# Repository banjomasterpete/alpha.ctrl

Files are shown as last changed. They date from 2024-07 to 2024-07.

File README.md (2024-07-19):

# alpha.ctrl
An open source Sysex controller for the Roland Alpha Juno

The Alpha Juno is a classic synthesizer with patches ranging from lush pads to the ‘Hoover’, but it’s also annoying to program. All parameter changes are done using 2 membrane keys and the alpha dial, this is adequate for making small changes but building patches from scratch can turn to agony. If it was the 80’s, the Alpha Juno could have been purchased with the optional programmer, the PG-300. This controller was specifically built for the Alpha 1 and 2 and restored the individual parameter change functions of previous Junos. In the 2020’s however, the PG-300s are often going for twice the price of the Juno, if you can even find one! There are other options available in software applications, custom MIDI controller layouts, and a few third party controllers. I’ve found the third party controllers to be unavailable or nearly as expensive as the originals, so this led me to design my own instead.

The alpha.ctrl can be built inexpensively, and its open source design makes it further modifiable by each user. I really encourage anyone to make modifications to it, I’m sure there are further optimizations to make than I could find.

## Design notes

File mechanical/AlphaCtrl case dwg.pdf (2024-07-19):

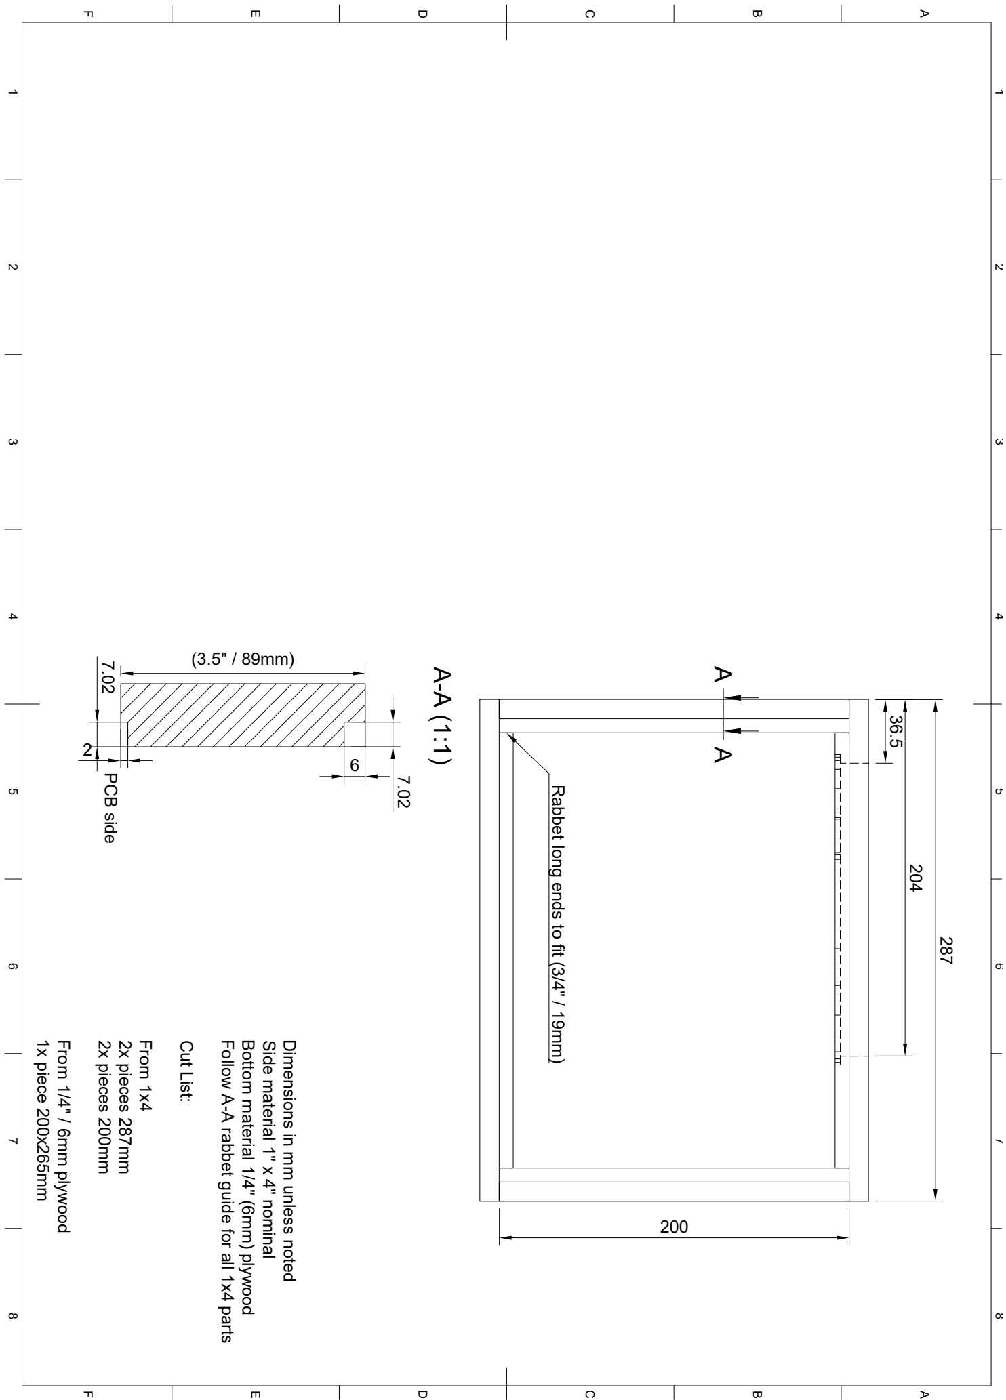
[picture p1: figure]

### 1 A 2 3 4 5 6 7 8 1 2 3 4 5 6 7 8 FEDCB FEDCBA 287

200 A-A (1:1) | A A2 PCB side | 6 | 7.02 7.02 1x piece 200x265mm From 1/4" / 6mm plywood | 2x pieces 200mm ²x pieces 287mm From 1x4 | Cut List: | Follow A-A rabbet guide for all 1x4 parts Bottom material 1/4" (6mm) plywood Side material 1" x 4" nominal Dimensions in mm unless noted
(3.5" / 89mm) | Rabbet long ends to fit (3/4" / 19mm) | 36.5 204

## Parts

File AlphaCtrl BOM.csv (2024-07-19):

Item | Qty | Reference(s) | Value | LibPart | Footprint | Tayda Part Number
1 | 1 | A1 | Arduino_Nano_Socket | arduino-library:Arduino_Nano_Socket | arduino-library:Arduino_Nano_Socket
2 | 2 | C1, C2 | 10u | Device:C_Polarized | Capacitor_THT:CP_Radial_D6.3mm_P2.50mm | ~
3 | 17 | C3, C4, C5, C6, C7, C8, C9, C10, C11, C12, C13, C14, C15, C16, C17, C18, C19 | 100n | Device:C | Capacitor_THT:C_Disc_D5.0mm_W2.5mm_P5.00mm | ~
4 | 1 | D1 | 1N914 | Diode:1N914 | Diode_THT:D_DO-35_SOD27_P7.62mm_Horizontal
5 | 1 | D2 | 1N4001 | Diode:1N4001 | Diode_THT:D_DO-41_SOD81_P10.16mm_Horizontal
6 | 1 | J1 | PWR | Connector_Generic:Conn_01x03 | Connector_BarrelJack:BarrelJack_Horizontal | A-3974
7 | 2 | MIDI_IN1, MIDI_OUT1 | ~ | Connector_Generic:Conn_01x07 | SynthParts:MIDI | A-1010
8 | 2 | PROG1, PWRSW1 | ~ | Connector_Generic:Conn_01x02 | Connector_PinHeader_2.54mm:PinHeader_1x02_P2.54mm_Vertical | ~
9 | 2 | R1, R2 | 10k | Device:R | Resistor_THT:R_Axial_DIN0207_L6.3mm_D2.5mm_P10.16mm_Horizontal | ~
10 | 24 | R3, R4, R5, R6, R7, R8, R9, R10, R11, R12, R13, R14, R15, R16, R17, R18, R19, R20, R21, R22, R23, R24, R25, R26 | 33k | Device:R | Resistor_THT:R_Axial_DIN0207_L6.3mm_D2.5mm_P10.16mm_Horizontal | ~
11 | 10 | R27, R28, R29, R30, R31, R32, R33, R34, R35, R36 | 20k | Device:R | Resistor_THT:R_Axial_DIN0207_L6.3mm_D2.5mm_P10.16mm_Horizontal | ~
12 | 4 | R37, R38, R39, R40 | 220R | Device:R | Resistor_THT:R_Axial_DIN0207_L6.3mm_D2.5mm_P10.16mm_Horizontal | ~
13 | 2 | R41, R42 | 1k | Device:R | Resistor_THT:R_Axial_DIN0207_L6.3mm_D2.5mm_P10.16mm_Horizontal | ~
14 | 25 | RV1, RV2, RV3, RV4, RV5, RV6, RV7, RV8, RV9, RV10, RV11, RV12, RV13, RV14, RV15, RV16, RV17, RV18, RV19, RV20, RV21, RV22, RV23, RV24, RV25 | 100k | Device:R_Potentiometer | Potentiometer_THT:Potentiometer_Bourns_PTV09A-1_Single_Vertical | X-3547
15 | 2 | SW1, SW2 | ~ | :JunoBtn_1 | SynthParts:JunoButtons | X-4850
16 | 10 | T1 - T10 | ~ | :SP8T_1 | RotarySwitch:Switch_Rotary 8POS | A-5950
17 | 5 | U1, U2, U3, U4, U5 | 4051 | 4xxx:4051 | Package_DIP:DIP-16_W10.16mm_LongPads
18 | 1 | U6 | 6N138 | Isolator:6N138 | Package_DIP:DIP-8_W7.62mm_LongPads
19 | 1 | U7 | L7805 | Regulator_Linear:L7805 | Package_TO_SOT_THT:TO-220-3_Vertical
20 | 2 | Jumpers |  | 2x1 0.1 inch header jumpers |  | A-1324
21 | 1 | 8 pin DIP socket
22 | 5 | 16 pin DIP socket
23 | 1 | female pinheaders (or arduino socket) |  | 0.1 inch female pinheaders
24 | 1 | Power rocker switch |  |  |  | A-6103
25 | 1 | DC Wall wart, 9V DC 1A center positive 5x2.5
26 | 35 | knobs |  | whatever kind you want!
27 | 6 | M3 wood screw |  | M3 x 10 | To mount the panel to the case
28 | 2 | M3 machine screw & nut |  | M3 x 10 | To mount the power switch to the case

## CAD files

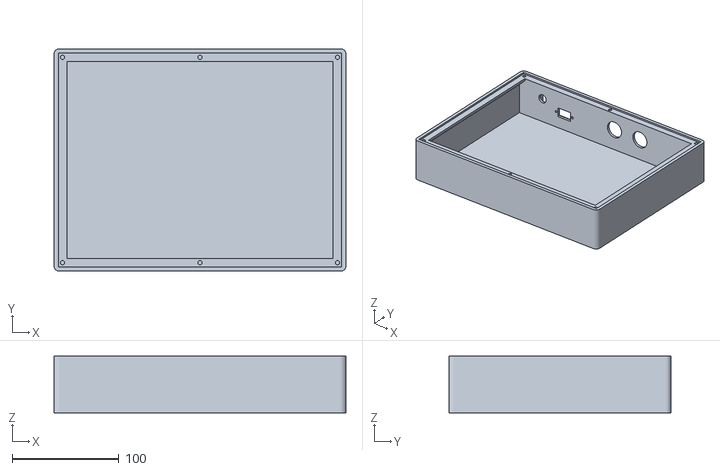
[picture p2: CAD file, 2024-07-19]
mechanical/AlphaCasePrint.stl
273.0 x 208.0 x 53.0

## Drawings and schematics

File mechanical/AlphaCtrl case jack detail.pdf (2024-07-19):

18

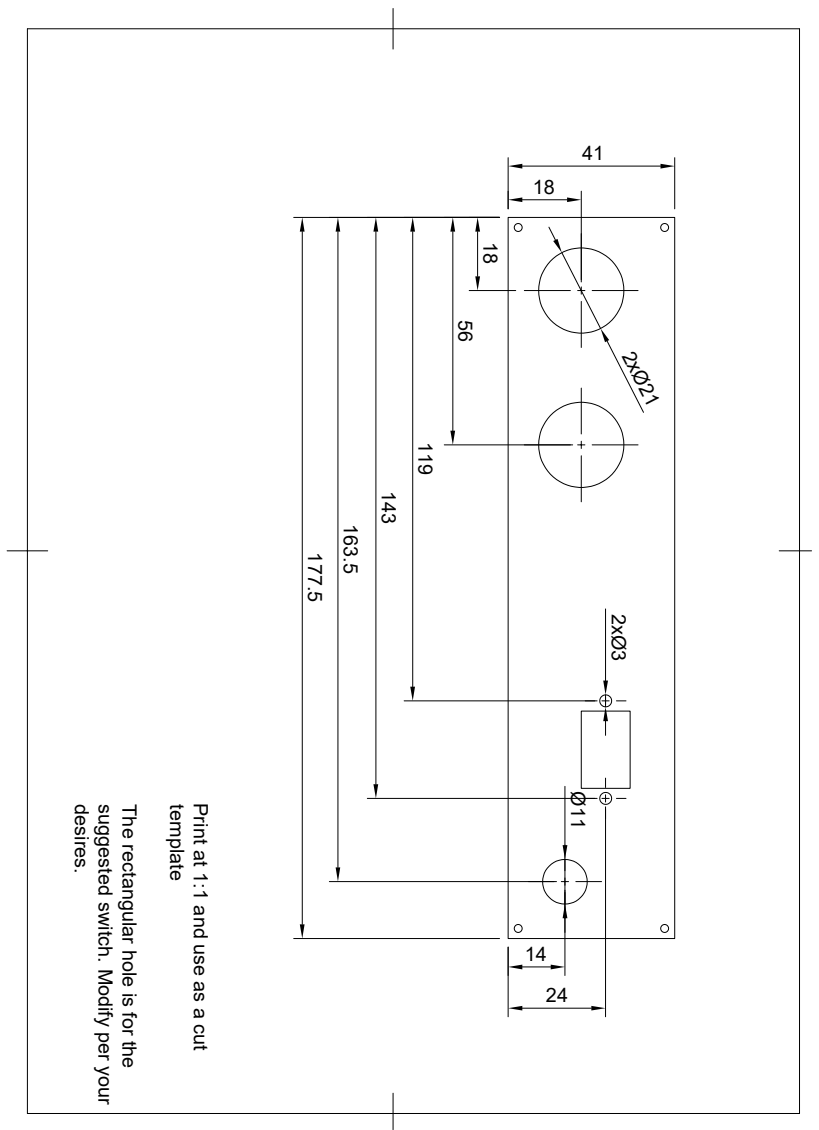
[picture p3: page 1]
2xØ21 2xØ3 Ø11 desires. suggested switch. Modify per your The rectangular hole is for the; template Print at 1:1 and use as a cut

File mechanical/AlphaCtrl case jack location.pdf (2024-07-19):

# 45 31.5 Sits against panel 6 9

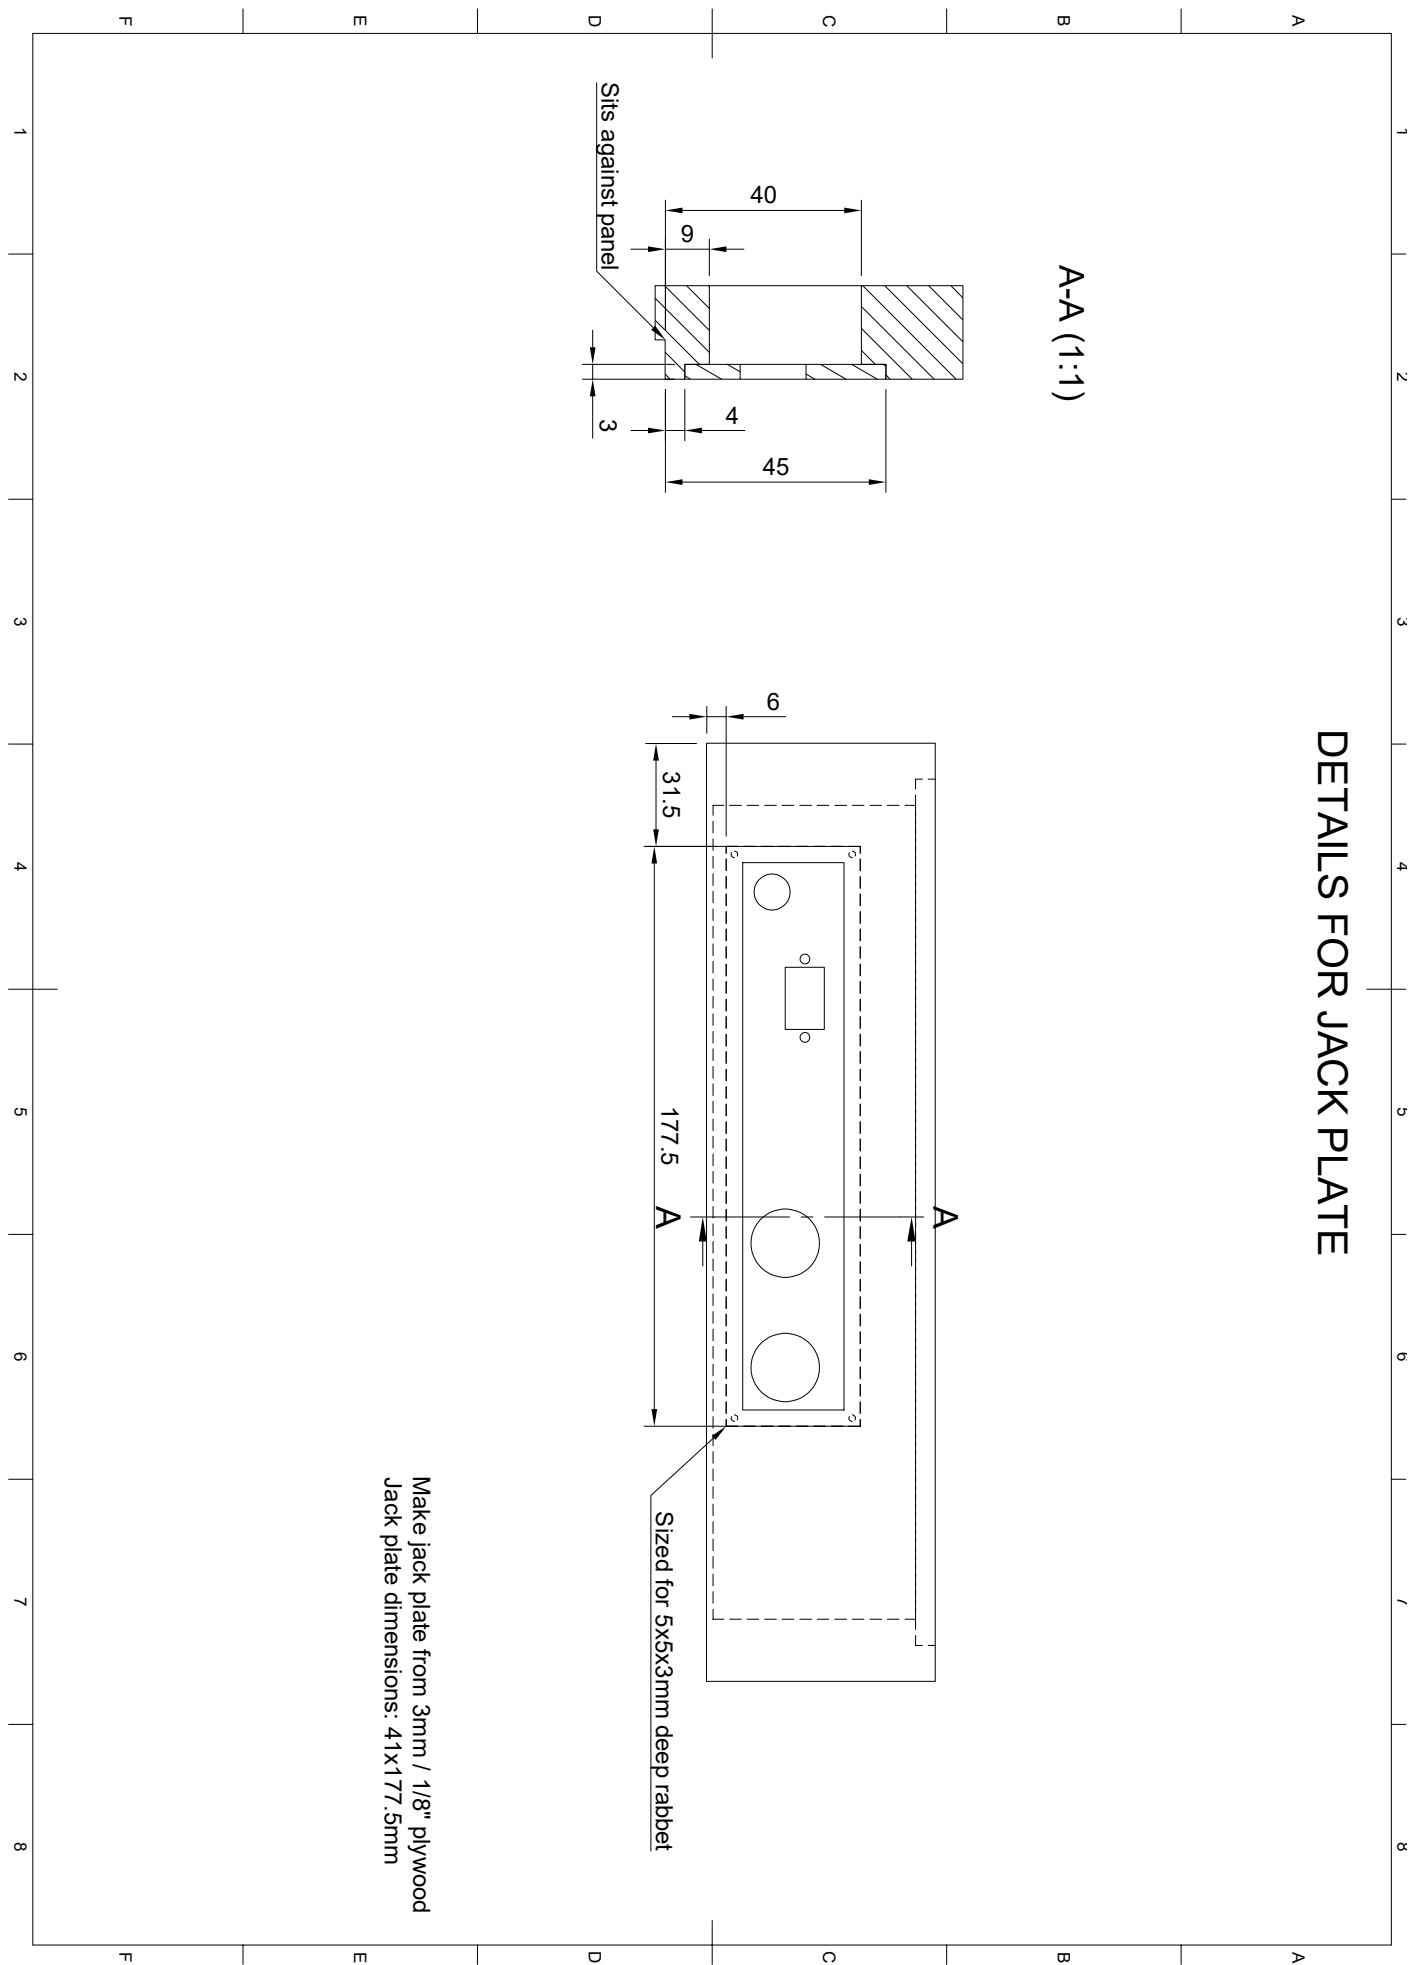
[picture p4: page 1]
DETAILS FOR JACK PLATE ³; 177.5 Jack plate dimensions: 41x177.5mm Make jack plate from 3mm / 1/8" plywood

1 A 2 3 4 5 6 7 8 1 2 3 4 5 6 7 8 FEDCB FEDCBA AA A-A (1:1) Sized for 5x5x3mm deep rabbet 4

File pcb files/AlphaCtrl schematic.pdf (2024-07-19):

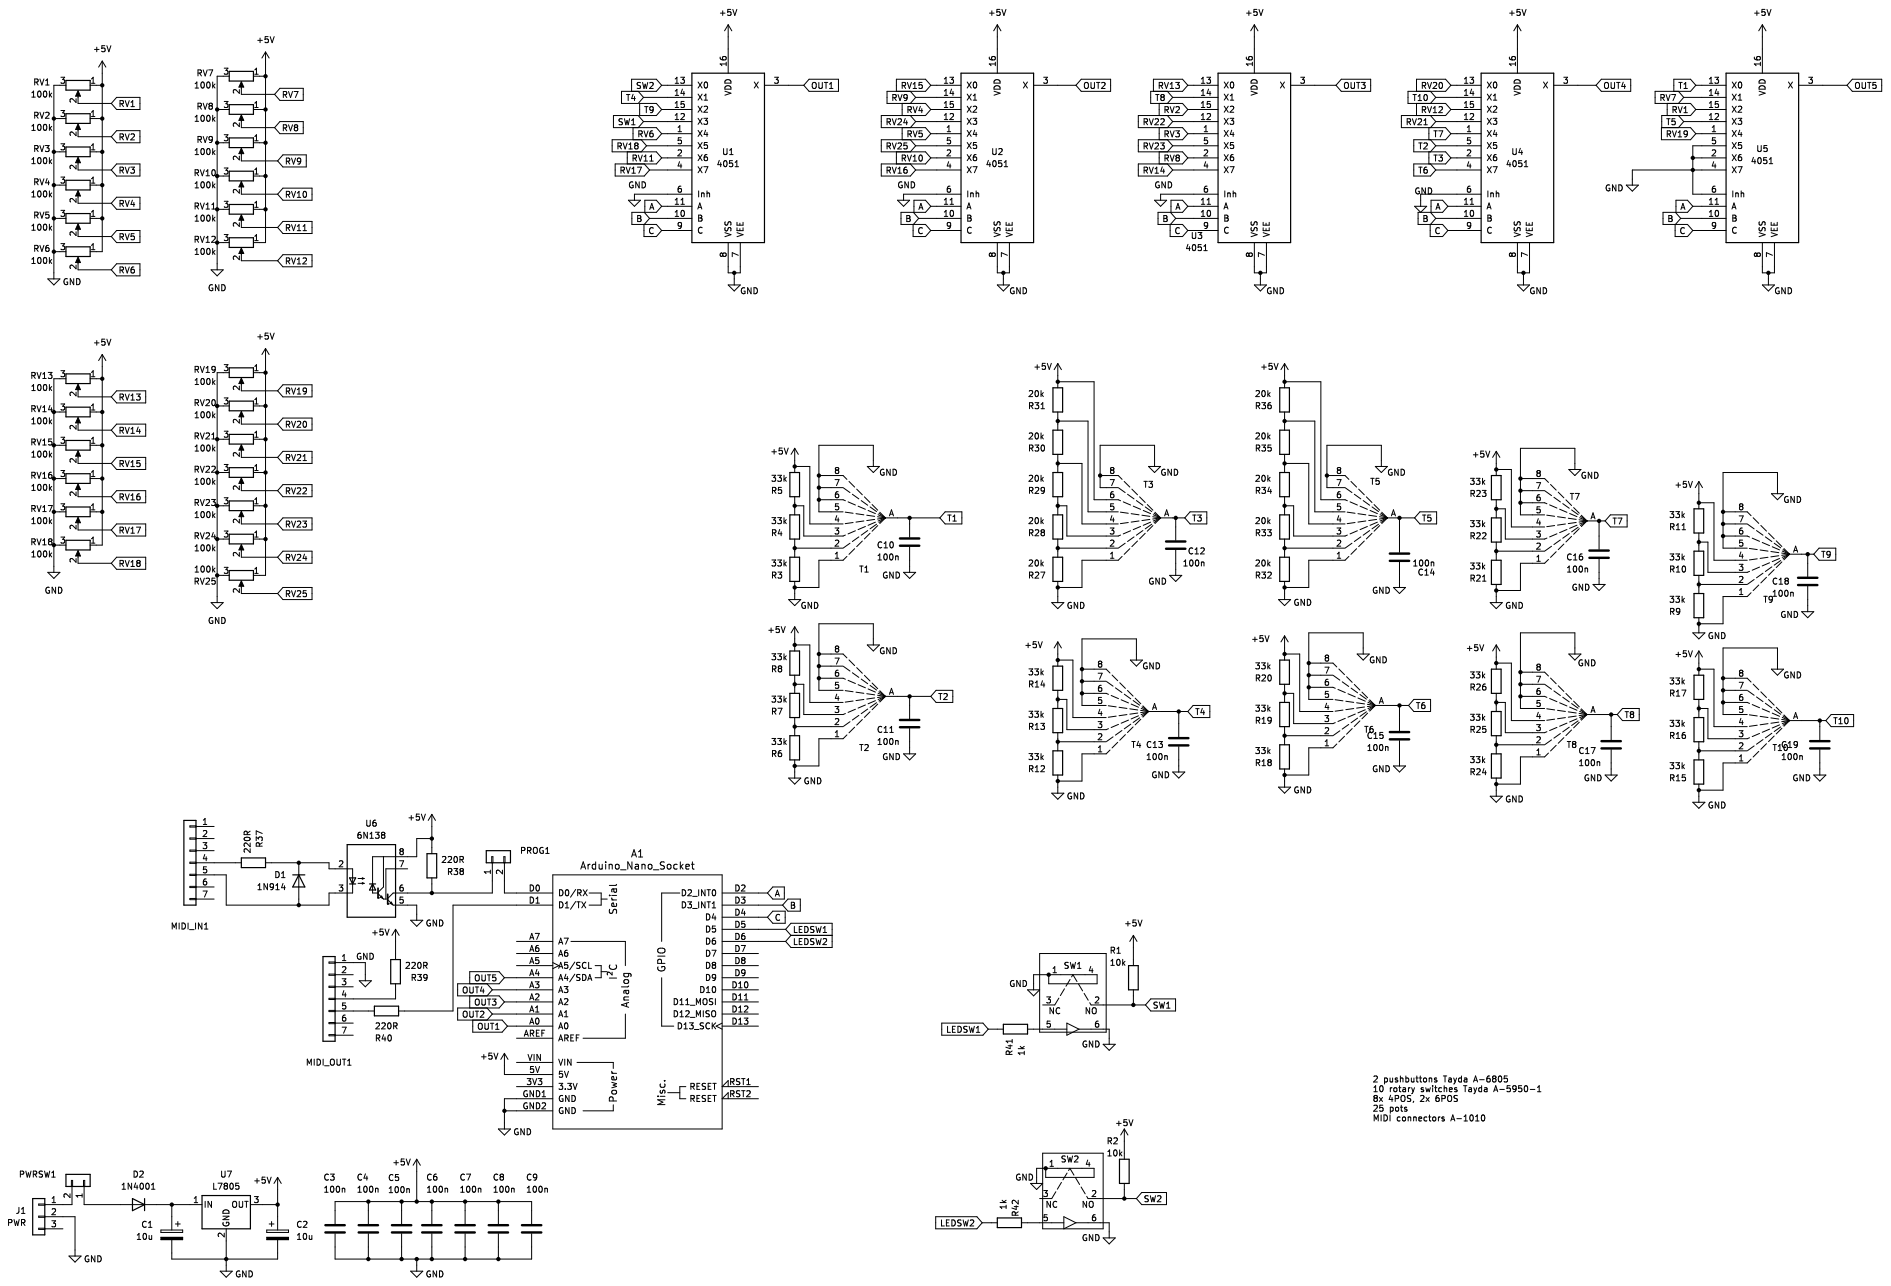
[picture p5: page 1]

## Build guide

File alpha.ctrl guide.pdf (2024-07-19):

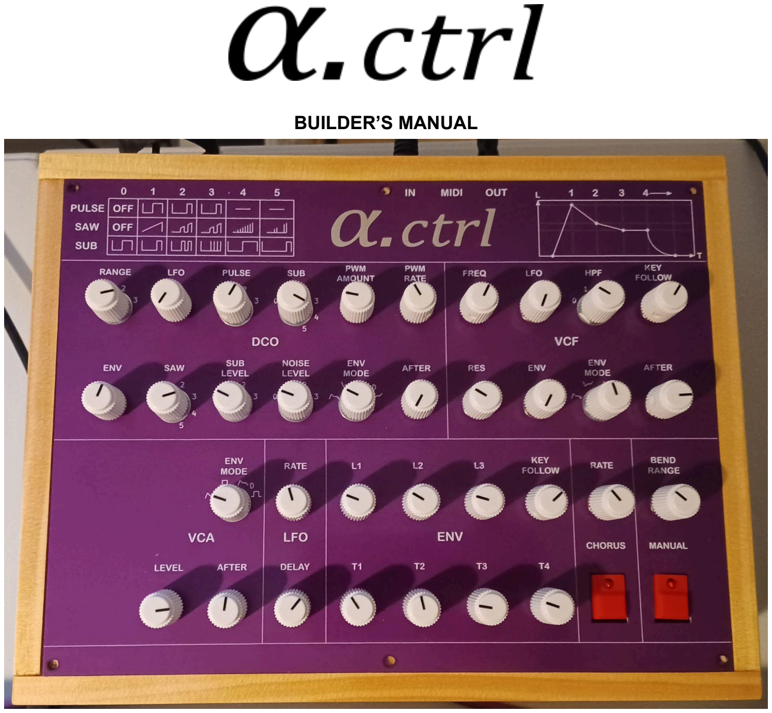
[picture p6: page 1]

BUILDER’S MANUAL

Build Guide
Order parts per the Bill of Materials, I was able to find all the parts on Tayda. Soldering the board components first (resistors, capacitors, chip sockets, etc.) before the panel components will leave you more room to work. The Bill of Materials contains the information needed to match each resistor number to its value. All of the ceramic capacitors are the same value throughout the board. Sockets are suggested for the multiplexers, optocoupler, and the Arduino. The jacks (power barrel jack, MIDI jacks) and the Arduino are soldered to the back side of the circuit board (the side the resistors go on). Pay attention to the silkscreen and you’ll be okay.

An Assembled Unit

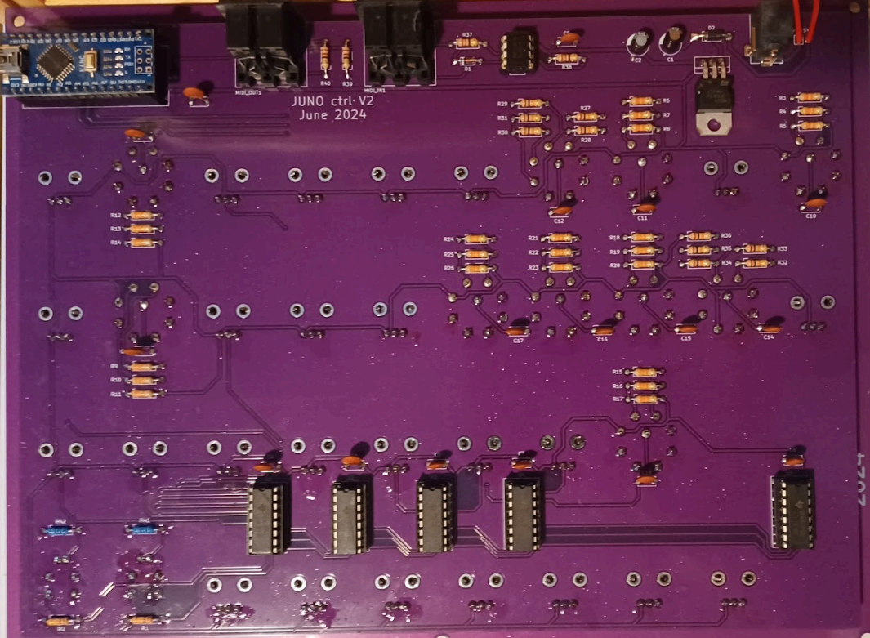
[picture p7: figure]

Before soldering panel components, attach the panel with the nuts from the pots & switches. This will ensure that all of the panel parts are aligned. The buttons can be finicky, solder 1 leg and maneuver it as needed with your off hand to get it aligned perfectly.

There are 2 sets of 2 pin jumpers: PWR and PROG. PWR is intended to be shorted with a rocker switch, any sort will do. PROG is necessary to disconnect the serial port from the MIDI circuit when the Arduino is being programmed. If the Arduino refuses to be programmed, make sure the PROG jumper is not connected!

PROG

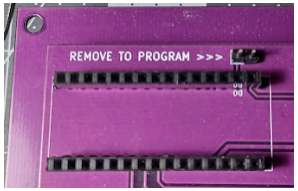
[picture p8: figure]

PWR

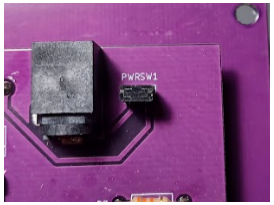
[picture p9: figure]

Speaking of power, the alpha.ctrl is powered by a 9V DC center positive wall wart. You probably have one of those laying around, right?

Enclosure
I opted to make a case out of some wood, mostly because my 3D printer is too small to make an enclosure this large. If you have a printer large enough, go for it! Mechanical drawings and an stl file are included in the repository.

Modifications
The jumpers can be removed if necessary. PWR can be replaced with a jumper wire, this will mean that the unit is always ON while the barrel jack is inserted. PROG can be replaced with a wire jumper, this means that the Arduino will need to be removed in order to program.

It may be desirable to mount the power and MIDI jacks directly to a separate panel instead of soldering to the circuit board. This could be helpful if you plan to use an alternative style of enclosure. Follow the schematic to determine where the pins should go.

Instead of running the MIDI channel change routine, I considered locating a DIP switch on the back side that would set the MIDI channel. This would, of course, require changes to the code.

Operations

The alpha.ctrl has 3 primary functions: individual parameter change, all parameter change, and MIDI channel change.These functions are the same as in the PG-300 owner’s manual.

NOTE: if no parameter changes are detected during operation, confirm that the MIDI EXCLUSIVE setting in the MIDI menu of the Juno is set to ON. The Juno will not accept parameter change messages if this setting is OFF.

Individual Parameter Change
Just move a control! The alpha.ctrl sends a Sysex message for each control change on the panel. These controls are the same as the parameter menu on the Juno, except now they’re easier to get to. All parameters work the same way they do per the Juno manual.

All Parameter Change
Pressing the Manual button will send the value of every control in its current location. You can think of this as a ‘hardware preset’ stored outside of the Juno’s memory. This control is necessary because the alpha.ctrl only sends a command when a parameter change is detected. If the Manual button is pressed accidentally, this change can be undone by reloading the preset.

MIDI Channel Change
The default MIDI channel of the alpha.ctrl is channel 1. In order to change this, power OFF the alpha.ctrl, set Noise Level and Sub Level as shown per the below table, then power ON the alpha.ctrl while holding the Manual button. The MIDI channel change is confirmed by 2 blinks from the Manual button LED. The channel is now updated and will be recalled every time the alpha.ctrl is powered on until this routine is run again.

MIDI Channel Change Table

NOISE LEVEL

0 | 1 | 2 | 3
SUB LEVEL | 0 | 1 | 2 | 3 | 4
| 1 | 5 | 6 | 7 | 8
| 2 | 9 | 10 | 11 | 12
| 3 | 13 | 14 | 15 | 16

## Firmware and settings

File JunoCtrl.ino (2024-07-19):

#include <MIDI.h>
#include <EEPROM.h>
MIDI_CREATE_DEFAULT_INSTANCE();

int MUXOUT [5] = {A0, A1, A2, A3, A4};
int ADD [3] = {2, 3, 4};
int LED1 = 5;
int LED2 = 6;

int timeout = 250; //time in ms where switch inputs are ignored for debounce

byte chorus = 0;

byte chan = 0; //sysex send channel, values 0-15 where channel = chan + 1
int stored = 0; //default EEPROM address
byte par [36] = {}; //(0-35), ignores MANUAL mode button
byte val  = 0; //0-1, 0-3, 0-5, 0-127 depending on value type

byte fifthval [37];
byte fourthval [37];
byte thirdval [37];
byte lastval [37];
byte rawval [37];
byte newval [37];   //stores new captured values for all control parameters
byte oldval [37];   //stores last saved values at loop end

byte bytemap(byte x, byte in_min, byte in_max, byte out_min, byte out_max) {
  return (x - in_min) * (out_max - out_min) / (in_max - in_min) + out_min;
}

byte toggleFour (byte readvalFour) {
  if (readvalFour < 22) {
    return 0;
  }
  else if (readvalFour < 63) {
    return 1;
  }
  else if (readvalFour < 105) {
    return 2;
  }
  else {
    return 3;
  }
}

byte toggleSix (byte readvalSix) {
  if (readvalSix < 12) {
    return 0;
  }
  else if (readvalSix < 37) {
    return 1;
  }
  else if (readvalSix < 63) {
    return 2;
  }
  else if (readvalSix < 89) {
    return 3;
  }
  else if (readvalSix < 113) {
    return 4;
  }
  else {
    return 5;
  }
}

void setup() {
  //Serial.begin (31250);
  byte ManualRead;
  byte NoiseRead;
  byte SubRead;

  if (EEPROM.read(stored) > 15) {
    EEPROM.update (stored, 0);
  }

  pinMode (ADD [0], OUTPUT);
  pinMode (ADD [1], OUTPUT);
  pinMode (ADD [2], OUTPUT);

  pinMode (LED1, OUTPUT);
  pinMode (LED2, OUTPUT);

  delay (100);

  digitalWrite (ADD [0], 0);
  digitalWrite (ADD [1], 0);
  digitalWrite (ADD [2], 0);

  ManualRead = byte(analogRead (MUXOUT [0]) / 8);

  if ((ManualRead) > 42) {
    
    digitalWrite (ADD [0], 1);
    digitalWrite (ADD [1], 1);
    digitalWrite (ADD [2], 1);

    SubRead = byte(analogRead (MUXOUT [3]) / 8);
    SubRead = toggleFour (SubRead);

    digitalWrite (ADD [0], 0);
    digitalWrite (ADD [1], 0);
    digitalWrite (ADD [2], 1);

    NoiseRead = byte(analogRead (MUXOUT [3]) / 8);
    NoiseRead = toggleFour (NoiseRead);


    chan = NoiseRead + (4 * SubRead);
    EEPROM.update (stored, chan);
    /*
    MIDI CHANNELS GUIDE (accounts for chan being 0 indexed)

             NOISE LEVEL
          | 0   1   2   3
          |---------------
      S 0 | 1   2   3   4
      U   |
      B 1 | 5   6   7   8
      L   |
      E 2 | 9   10  11  12
      V   |
      E 3 | 13  14  15  16
      L   |
    */

    int q = 0;

    while (q < 3) {
      digitalWrite (LED2, HIGH);
      delay (300);
      digitalWrite (LED2, LOW);
      delay (300);    
      q++;
    }


  
  }
  chan = EEPROM.read (stored);
  MIDI.begin(chan + 1); //listening on channel set by chan

}

void singleSend (byte param, byte value) { //this function is equal to IPR routine in the PG-300 manual
  byte singleParam [10] = {0xF0, 0x41, 0x36, chan, 0x23, 0x20, 0x01, param, value, 0xF7};
  MIDI.sendSysEx (sizeof(singleParam), singleParam, true);
  //Serial.print (param);
  //Serial.println (value);
}

void manualSend () { //this function is equal to APR routine in the PG-300 manual
  byte allParams [44] = {0xF0, 0x41, 0x35, chan, 0x23, 0x20, 0x01, 0, 0, 0, 0, 0, 0, 0, 0, 0, 0, 0, 0, 0, 0, 0, 0, 0, 0, 0, 0, 0, 0, 0, 0, 0, 0, 0, 0, 0, 0, 0, 0, 0, 0, 0, 0, 0xF7};
  
  int m = 0;

  while (m < 35) {
    allParams [m + 7] = par [m];
    m++;
  }
  MIDI.sendSysEx (sizeof(allParams), allParams, true);
  /*int count = 0;
  while (count < 44) {
    Serial.println(allParams[count]);
    count++;
  }
  */
}

void loop() {
  MIDI.read();

  int i = 0;

  while (i < 5) {

    int j = 0;

    while (j < 8) {
      int inc = (i*8) + j;
      
      digitalWrite(ADD [0], bitRead (j, 0)); //ADD array is pins 2, 3, 4 that set address pins A, B, C of the 5X 4051s
      digitalWrite(ADD [1], bitRead (j, 1));
      digitalWrite(ADD [2], bitRead (j, 2));

      if (inc <= 36) {                                       //count goes up to 39 but there are only 37 controls
        
        //oldval [inc] = newval [inc];                                //newval is an array of values read from the controls, stored in mux order
        //newval [inc] = byte ((analogRead (MUXOUT [i])) / 8); //for each address setting, read the COM pin of all 5x 4051s on A0 - A4
        
        fifthval [inc] = fourthval [inc];
        fourthval [inc] = thirdval [inc];
        thirdval [inc] = lastval [inc];
        lastval [inc] = rawval [inc];
        rawval [inc] = byte ((analogRead (MUXOUT [i])) / 8);

        oldval [inc] = newval [inc];
        newval [inc] = (rawval [inc] + lastval [inc] + thirdval [inc] + fourthval [inc] + fifthval [inc]) / 5;

      }
      else {
        break;
      }
      j++;
    }
    i++;
  }

  //store values so their array location matches PG300 manual
  for (int k = 0; k < 37; k++) {
    unsigned long checkTime = millis();
    if (newval [k] != oldval [k]) {
      
    switch (k) {
      case 0: //MANUAL, 0-1 this command sends ALL values 0-35 in one message
        static unsigned long manualTime;
        if (newval [k] < 42 && (checkTime - manualTime > timeout)) {
          digitalWrite (LED2, HIGH);
          manualSend();
          manualTime = checkTime;
        }
        else {
          digitalWrite (LED2, LOW);

        }
      break;

      case 1: //HPF CUTOFF FREQ, 0-3
        par [9] = toggleFour (newval[k]);
        singleSend (9, par [9]);
      break;

      case 2: //VCF ENV MODE, 0-3
        par [1] = toggleFour (newval[k]);
        singleSend (1, par [1]);
      break;

      case 3: //CHORUS, 0-1
        static unsigned long chorusTime;
        if (newval [k] < 42 && chorus == 0 && (checkTime - chorusTime > timeout)) {
          digitalWrite (LED1, HIGH);
          chorus = 1;
          par [10] = 1;
          singleSend (10, par [10]);
          chorusTime = checkTime;
        }
        else if (newval [k] < 42 && chorus == 1 && (checkTime - chorusTime > timeout)) {
          digitalWrite (LED1, LOW);
          chorus = 0;
          par [10] = 0;
          singleSend (10, par [10]);
          chorusTime = checkTime;
        }
      break;

      case 4: //VCF KEY FOLLOW, 0-127
        par [20] = newval [k];
        singleSend (20, par [20]);
      break;

      case 5: //BENDER RANGE, 0-12
        par [35] = bytemap (newval[k], 0, 127, 0, 12);
        singleSend (35, par [35]);
      break;

      case 6: //VCF AFTER DEPTH, 0-127
        par [21] = newval [k];
        singleSend (21, par [21]);
      break;

      case 7: //CHORUS RATE, 0-127
        par [34] = newval [k];
        singleSend (34, par [34]);
      break;

      case 8: //ENV L3, 0-127 (SUSTAIN LEVEL)
        par [31] = newval [k];
        singleSend (31, par [31]);
      break;

      case 9: //VCF RESONANCE, 0-127
        par [17] = newval [k];
        singleSend (17, par [17]);
      break;

      case 10: //VCF CUTOFF FREQ, 0-127
        par [16] = newval [k];
        singleSend (16, par [16]);
      break;

      case 11: //ENV T3, 0-127 (DECAY TIME)
        par [30] = newval [k];
        singleSend (30, par [30]);
      break;

      case 12: //VCF LFO MOD DEPTH, 0-127
        par [18] = newval [k];
        singleSend (18, par [18]);
      break;

      case 13: //ENV T4, 0-127 (RELEASE TIME)
        par [32] = newval [k];
        singleSend (32, par [32]);
      break;

      case 14: //VCF ENV MOD DEPTH, 0-127
        par [19] = newval [k];
        singleSend (19, par [19]);
      break;

      case 15: //ENV KEY FOLLOW, 0-127
        par [33] = newval [k];
        singleSend (33, par [33]);
      break;

      case 16: //ENV L1, 0-127 (ATTACK LEVEL)
        par [27] = newval [k];
        singleSend (27, par [27]);
      break;

      case 17: //DCO ENV MODE, 0-3
        par [0] = toggleFour (newval[k]);
        singleSend (0, par [0]);
      break;

      case 18: //DCO PWM DEPTH, 0-127
        par [14] = newval [k];
        singleSend (14, par [14]);
      break;

      case 19: //ENV T1, 0-127 (ATTACK TIME)
        par [26] = newval [k];
        singleSend (26, par [26]);
      break;

      case 20: //DCO PWM RATE, 0-127
        par [15] = newval [k];
        singleSend (15, par [15]);
      break;

      case 21: //ENV T2, 0-127 (BREAK TIME)
        par [28] = newval [k];
        singleSend (28, par [28]);
      break;

      case 22: //DCO AFTER DEPTH, 0-127
        par [13] = newval [k];
        singleSend (13, par [13]);
      break;

      case 23: //ENV L2, 0-127 (BREAK LEVEL)
        par [29] = newval [k];
        singleSend (29, par [29]);
      break;
   
      case 24: //VCA AFTER DEPTH, 0-127
        par [23] = newval [k];
        singleSend (23, par [23]);
      break;

      case 25: //VCA ENV MODE, 0-3
        par [2] = toggleFour (newval[k]);
        singleSend (2, par [2]);
      break;

      case 26: //LFO RATE, 0-127
        par [24] = newval [k];
        singleSend (24, par [24]);
      break;
    
      case 27: //LFO DELAY TIME, 0-127
        par [25] = newval [k];
        singleSend (25, par [25]);
      break;

      case 28: //DCO NOISE LEVEL, 0-3
        par [8] = toggleFour (newval[k]);
        singleSend (8, par [8]);
      break;

      case 29: //DCO WAVE PULSE, 0-3
        par [3]  = toggleFour (newval[k]);
        singleSend (3, par [3]);
      break;

      case 30: //DCO WAVE SUB, 0-5
        par [5] = toggleSix (newval[k]);
        singleSend (5, par [5]);
      break;

      case 31: //DCO SUB LEVEL, 0-3
        par [7] = toggleFour (newval[k]);
        singleSend (7, par [7]);
      break;

      case 32: //DCO RANGE, 0-3
        par [6] = toggleFour (newval[k]);
        singleSend (6, par [6]);
      break;

      case 33: //DCO ENV MOD DEPTH, 0-127
        par [12] = newval [k];
        singleSend (12, par [12]);
      break;

      case 34: //DCO LFO MOD DEPTH, 0-127
        par [11] = newval [k];
        singleSend (11, par [11]);
      break;

      case 35: //DCO WAVE SAW, 0-5
        par [4] = toggleSix (newval[k]);
        singleSend (4, par [4]);
      break;

      case 36: //VCA LEVEL, 0-127
        par [22] = newval [k];
        singleSend (22, par [22]);
      break;
    
      }
    }
  }
}

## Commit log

2024-07-19 Create gerbers
2024-07-19 Rename JunoCtrl schematic.pdf to AlphaCtrl schematic.pdf
2024-07-19 Update and rename JunoCtrl.kicad_sch to AlphaCtrl.kicad_sch
    [AlphaCtrl.kicad_sch]
2024-07-19 Rename JunoCtrl case dwg.pdf to AlphaCtrl case dwg.pdf
2024-07-19 Rename JunoCtrl case jack detail.pdf to AlphaCtrl case jack detail.pdf
2024-07-19 Rename JunoCtrl case jack location.pdf to AlphaCtrl case jack location.pdf
2024-07-19 Update and rename AlphaCtrl - JunoCtrl.csv to AlphaCtrl BOM.csv
    [AlphaCtrl BOM.csv]
